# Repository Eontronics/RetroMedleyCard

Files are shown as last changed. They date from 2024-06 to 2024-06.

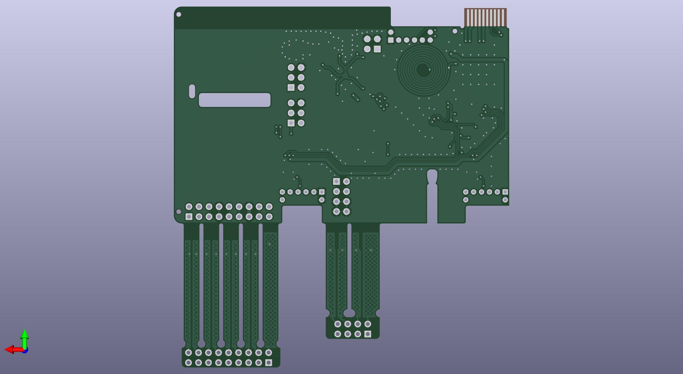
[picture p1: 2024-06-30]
Images/RMC_Back_Ortho.jpg

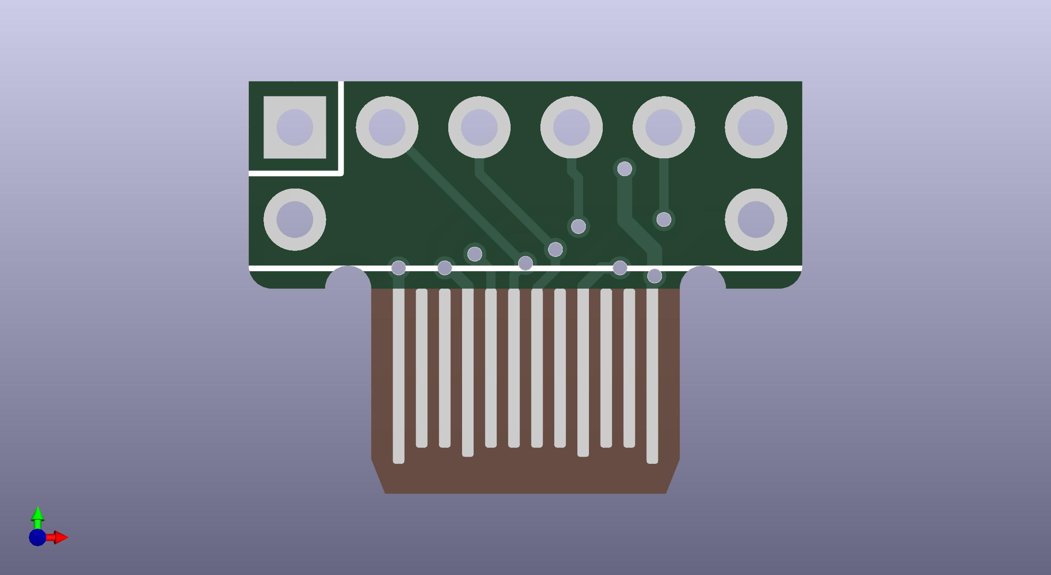
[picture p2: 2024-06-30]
Images/RMC_USBCT_Front_Ortho.jpg

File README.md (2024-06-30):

# RetroMedleyCard
Repository containing the RetroMedleyCard hardware design files.

RetroMedleyCard is a buisiness card sized PCB created for the [Hackaday 2024 Business Card Contest](https://hackaday.io/contest/195949-2024-business-card-contest) that aims to run a range of emulators with support for USB controllers, and output to full sized monitors/TVs, while maintaining a thicnkess <=2.0mm.

The Hackaday.io project page for RetroMedleyCard may be found at https://hackaday.io/project/196328-retromedleycard, which includes images of the physical hardware and testing

# Limitations
The current (first) iteration of RetroMedleyCard is severely limited by the ~2MB of onboard RAM, and various other issues:
* It has been successfully tested running Gameboy emulation without audio output, however other emulators often cause the system to crash immediately.
* The connectors are all formed using specially shaped PCB structures in order to maintain a thin form-factor, however these often fail to make reliable contact for audio, USB-C and SD card connections.
* Display output is limited to ~52fps @320x240 in RGB565, due to difficulty moving pixel data from the RP2040 PIO into the frame-buffer while remaining syncronised with commands sent over the same interface

It is intended to run a modified version of [retro-go](https://github.com/ducalex/retro-go), however firmware is not yet provided as it is currently a mess of rushed tweaks in an attempt to get a functional device.

As a result of these limitations I do not see it being worthwhile to improve the firmware for this version of RetroMedleyCard, as future iterations should aim to adress the lack of available memory, for which a more complete firmware can be written.

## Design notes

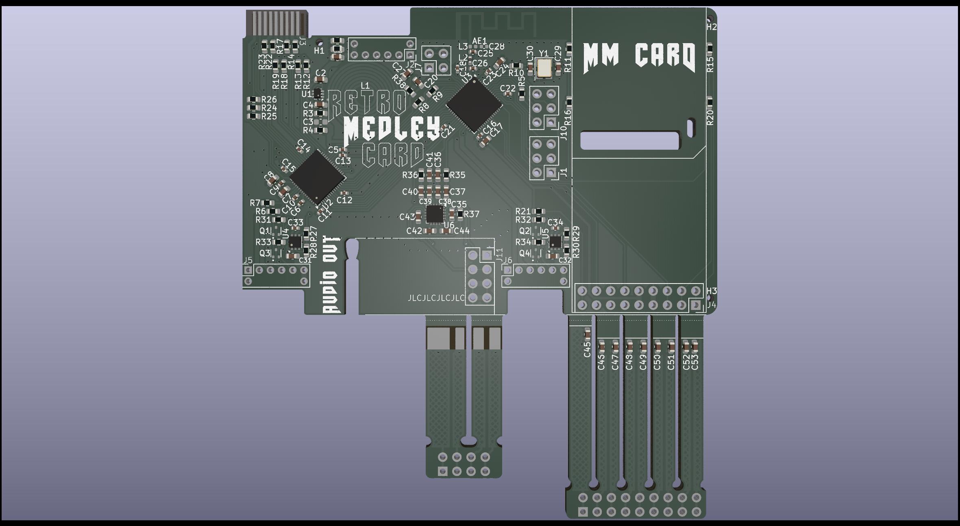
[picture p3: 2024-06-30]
Images/RMC_Front_Render.jpg

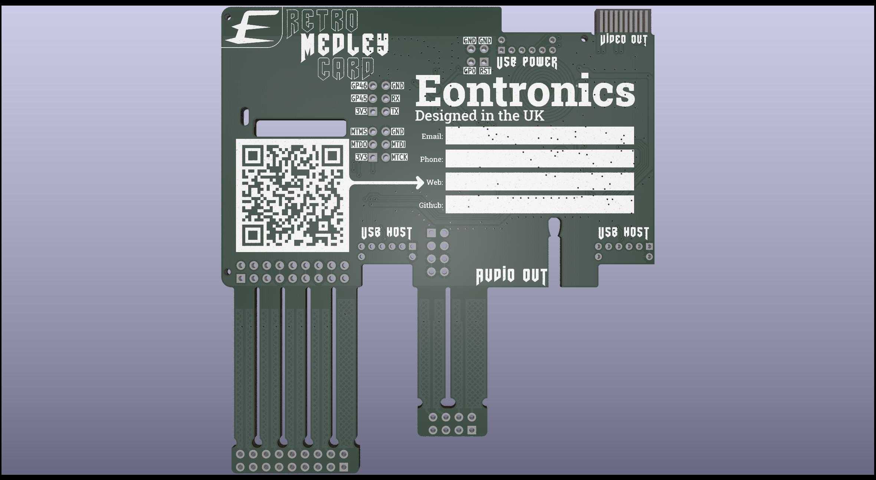
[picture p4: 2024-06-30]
Images/RMC_Back_Render.jpg

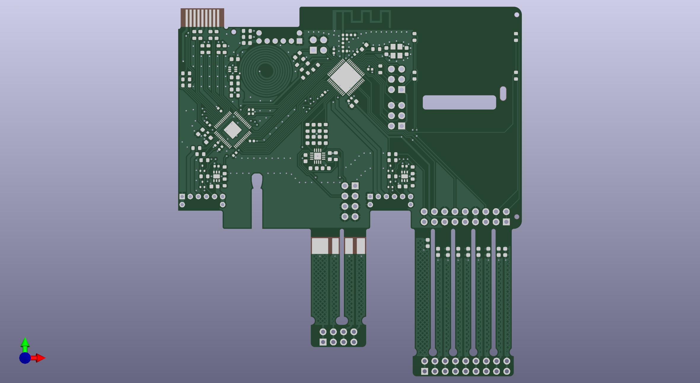
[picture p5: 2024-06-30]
Images/RMC_Front_Ortho.jpg

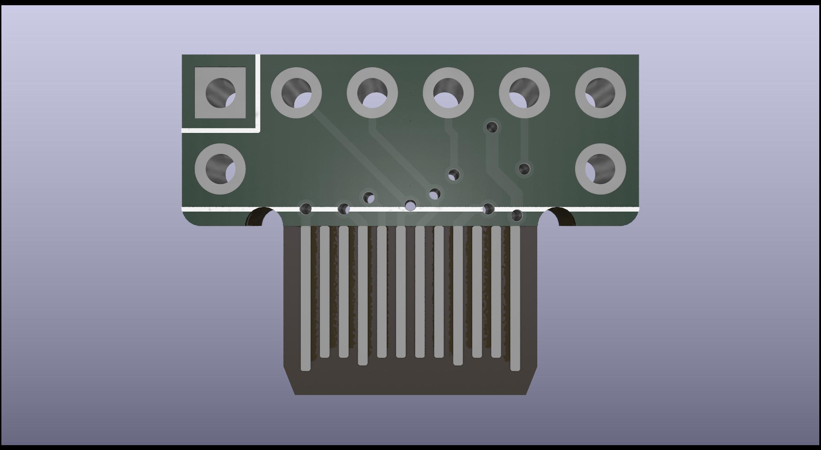
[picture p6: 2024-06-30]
Images/RMC_USBCT_Front_Render.jpg

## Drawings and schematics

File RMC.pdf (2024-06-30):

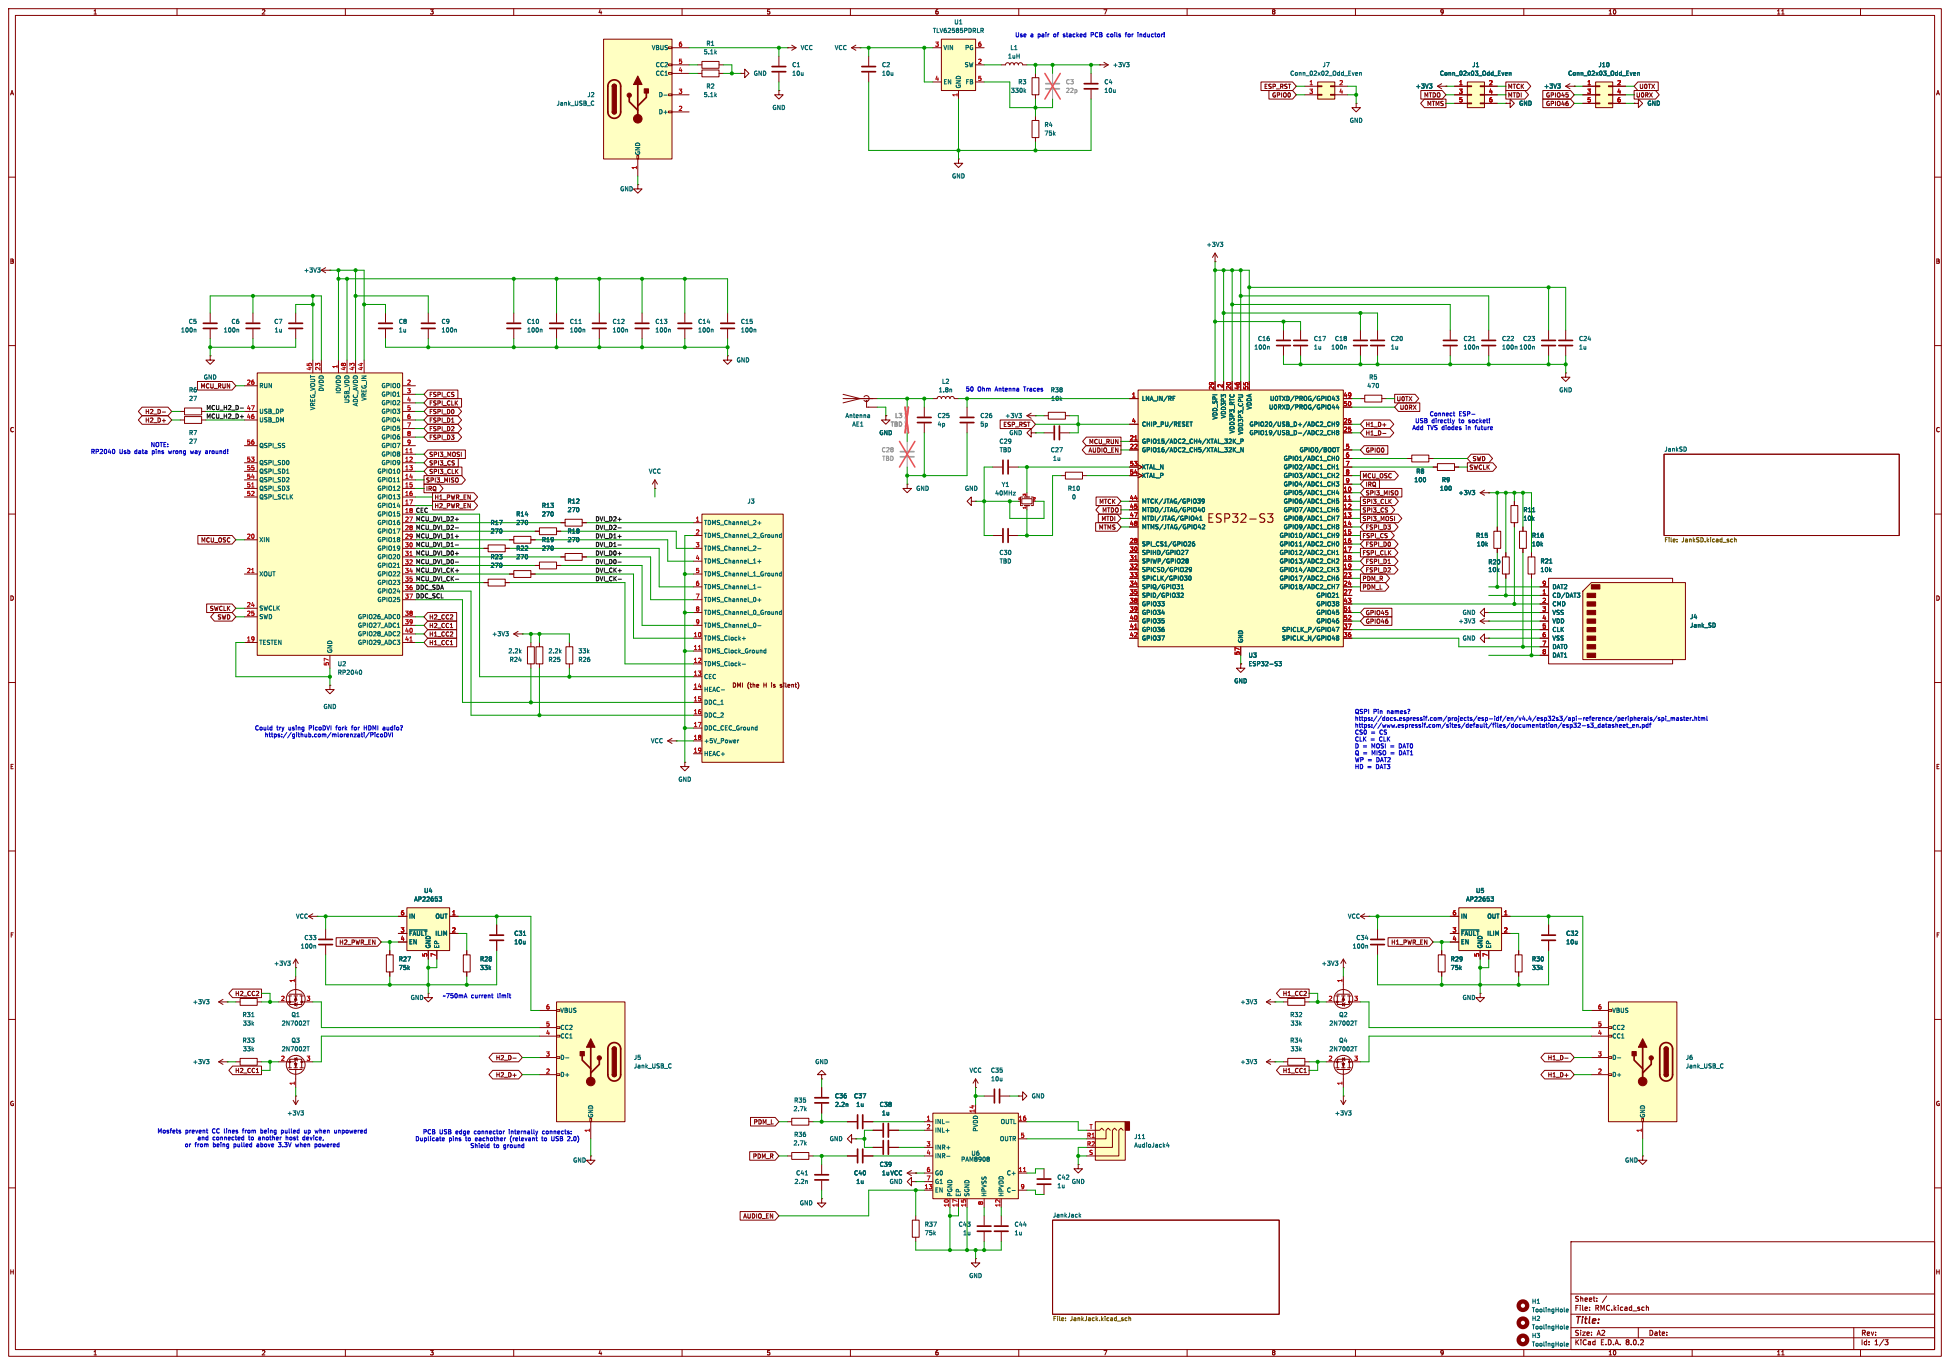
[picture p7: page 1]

1 SW 2 VIN 3 EN 4 FB 5 PG 6 U1 TLV62585PDRLR

Use a pair of stacked PCB coils for inductor! NOTE: RP2040 Usb data pins wrong way around!

GND
100n DMI (the H is silent) TDMS_Channel_2+ 1 TDMS_Clock+ 10 TDMS_Clock_Ground 11 TDMS_Clock- 12 CEC 13 HEAC- 14 DDC_1 15 DDC_2 16 DDC_CEC_Ground 17 +5V_Power 18 HEAC+ 19 TDMS_Channel_2_Ground 2 TDMS_Channel_2- 3 TDMS_Channel_1+ 4 TDMS_Channel_1_Ground 5 TDMS_Channel_1- 6 TDMS_Channel_0+ 7 TDMS_Channel_0_Ground 8 TDMS_Channel_0- 9

QSPI Pin names?
https://docs.espressif.com/projects/esp-idf/en/v4.4/esp32s3/api-reference/peripherals/spi_master.html
https://www.espressif.com/sites/default/files/documentation/esp32-s3_datasheet_en.pdf CS0 = CS CLK = CLK D = MOSI = DAT0 Q = MISO = DAT1 WP = DAT2 HD = DAT3

Could try using PicoDVI fork for HDMI audio?
https://github.com/mlorenzati/PicoDVI

~750mA current limit Mosfets prevent CC lines from being pulled up when unpowered

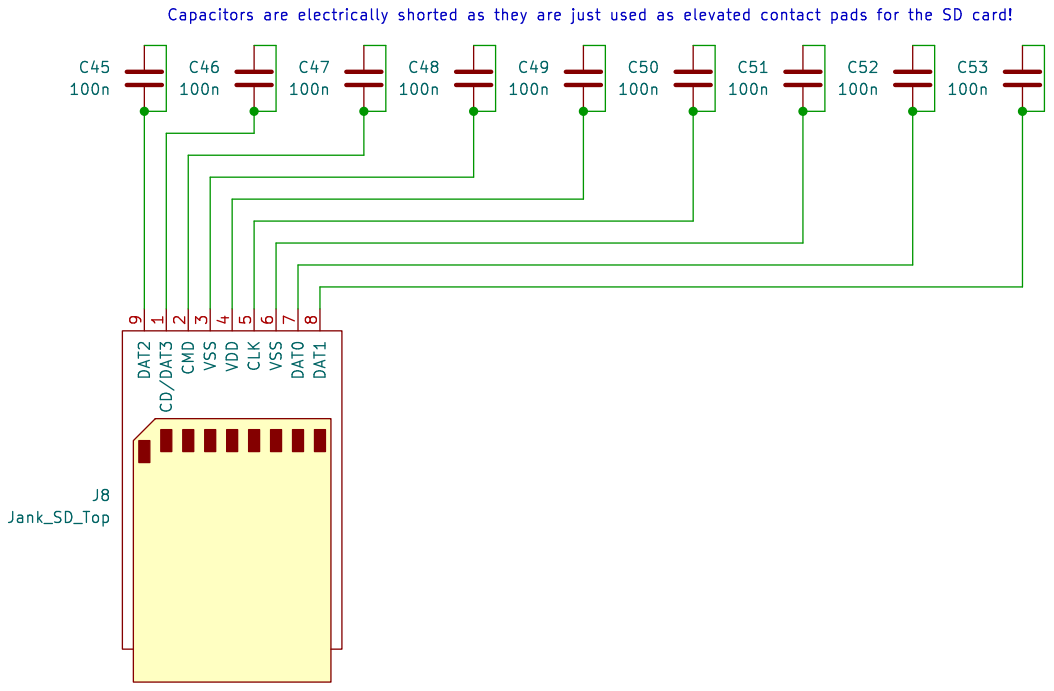
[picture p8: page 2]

1 CMD
Id: 2/3 Title: File: JankSD.kicad_sch Sheet: /JankSD/ CD/DAT3

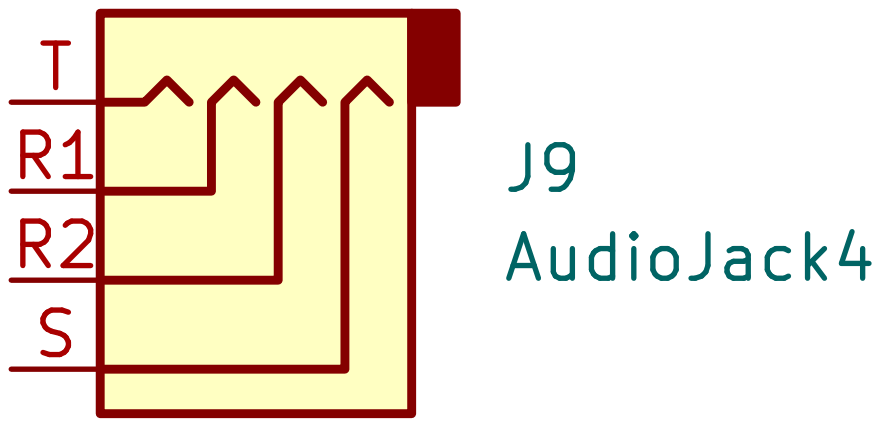
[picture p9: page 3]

Id: 3/3 Title: File: JankJack.kicad_sch Sheet: /JankJack/ R1 R2S

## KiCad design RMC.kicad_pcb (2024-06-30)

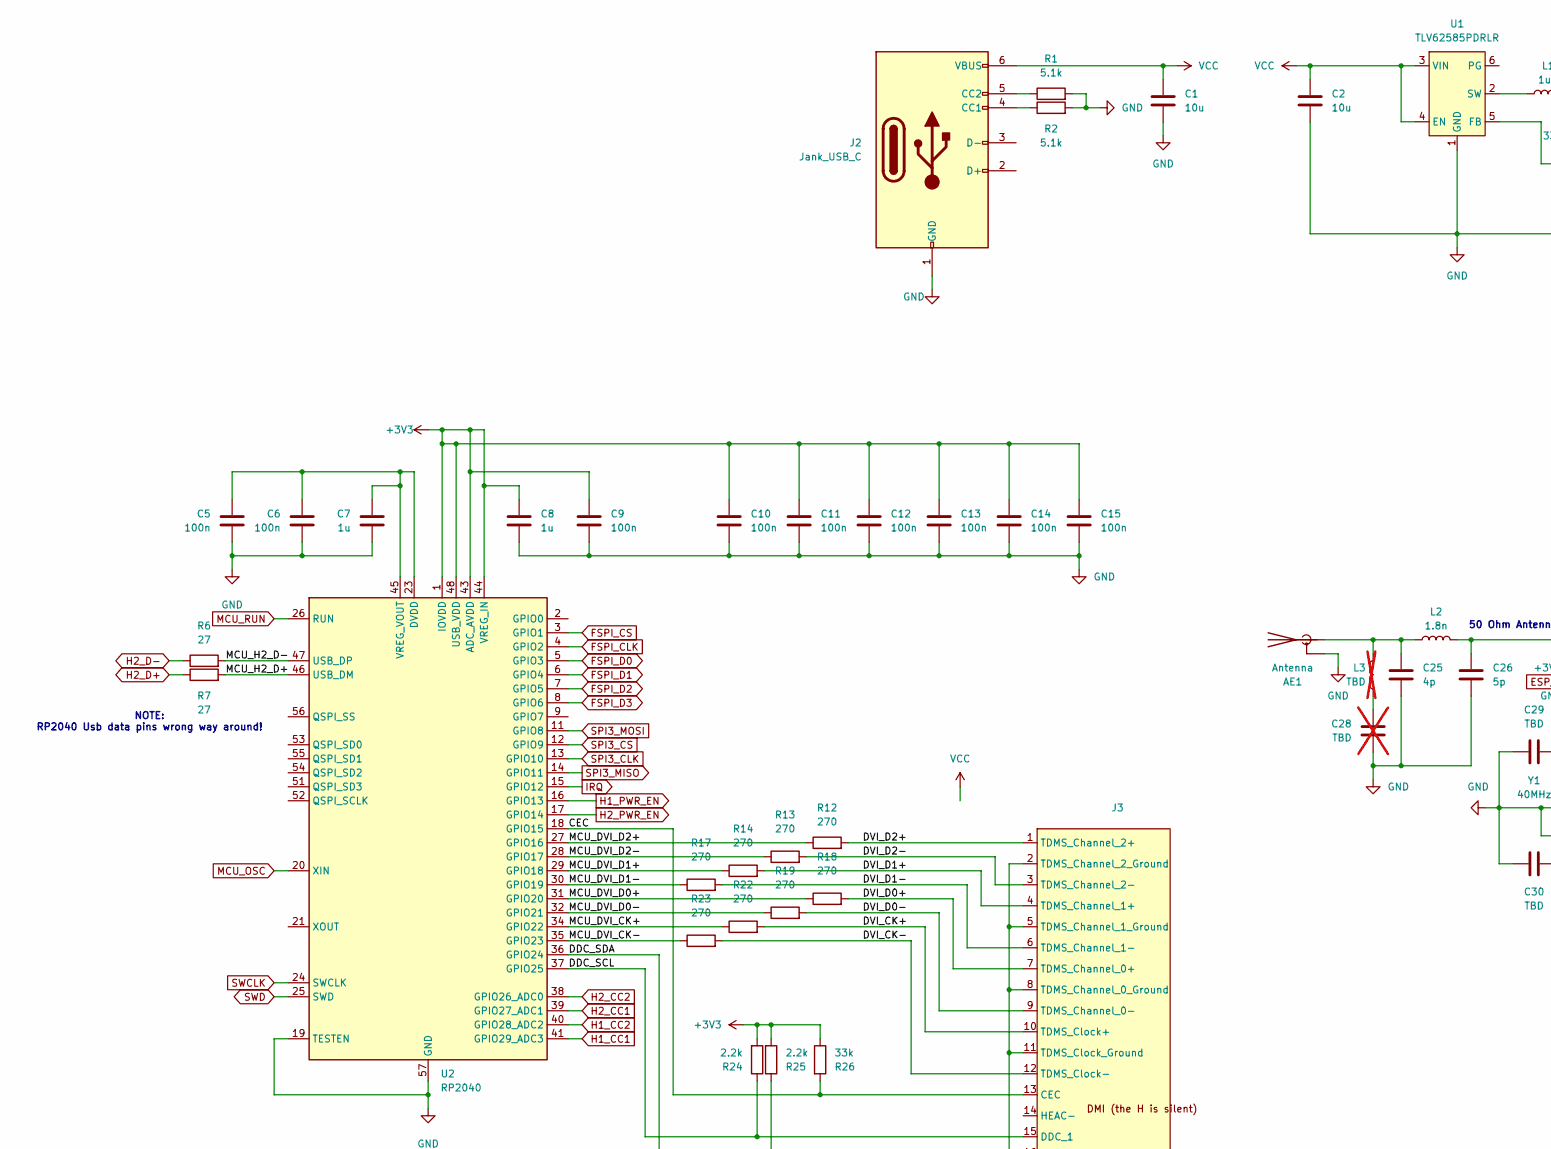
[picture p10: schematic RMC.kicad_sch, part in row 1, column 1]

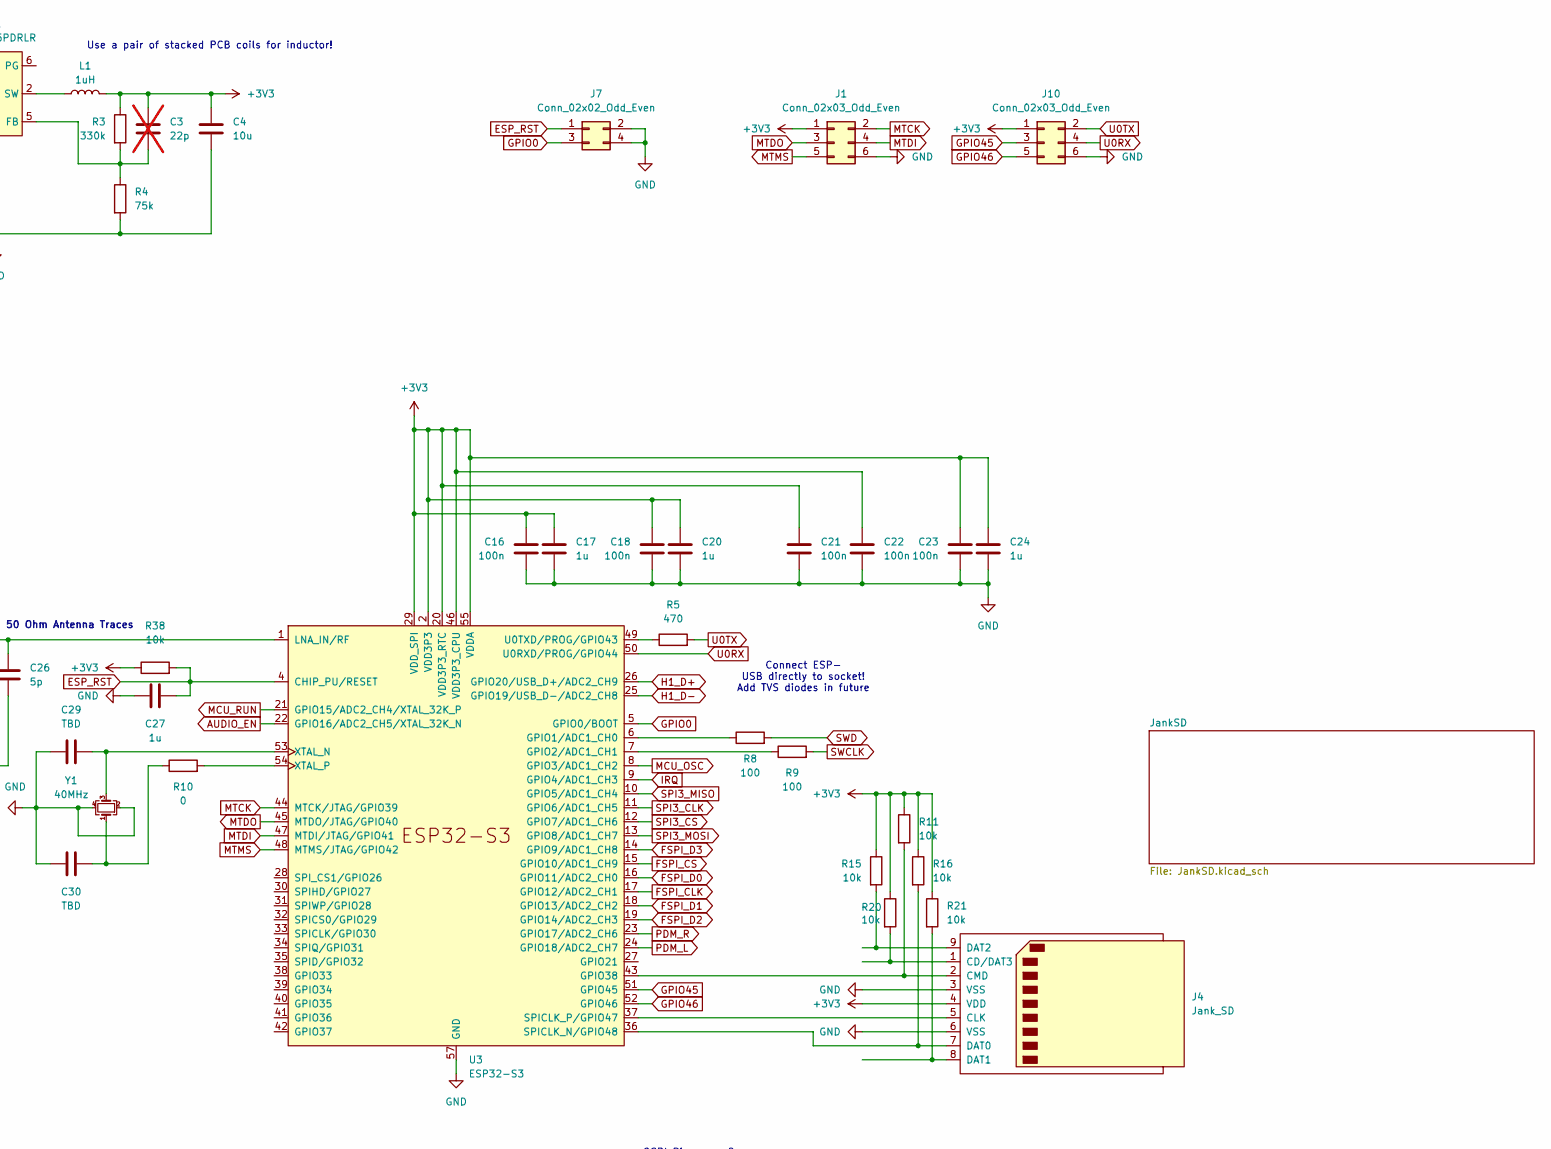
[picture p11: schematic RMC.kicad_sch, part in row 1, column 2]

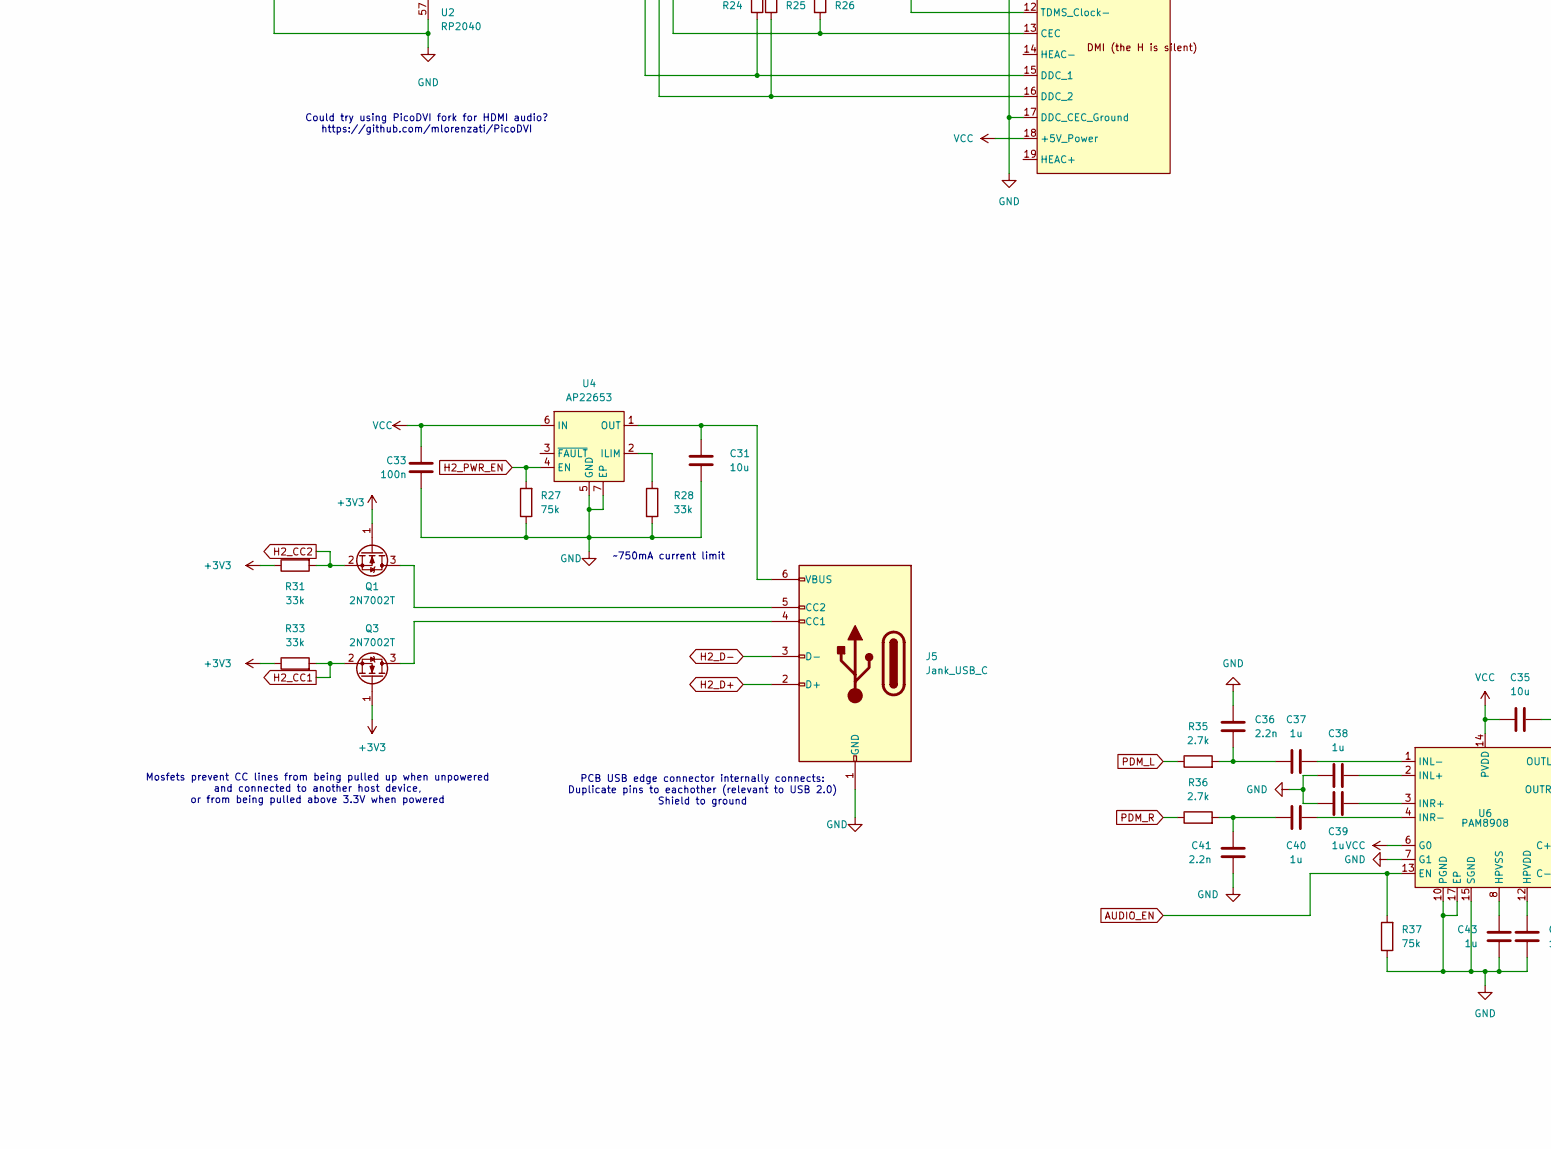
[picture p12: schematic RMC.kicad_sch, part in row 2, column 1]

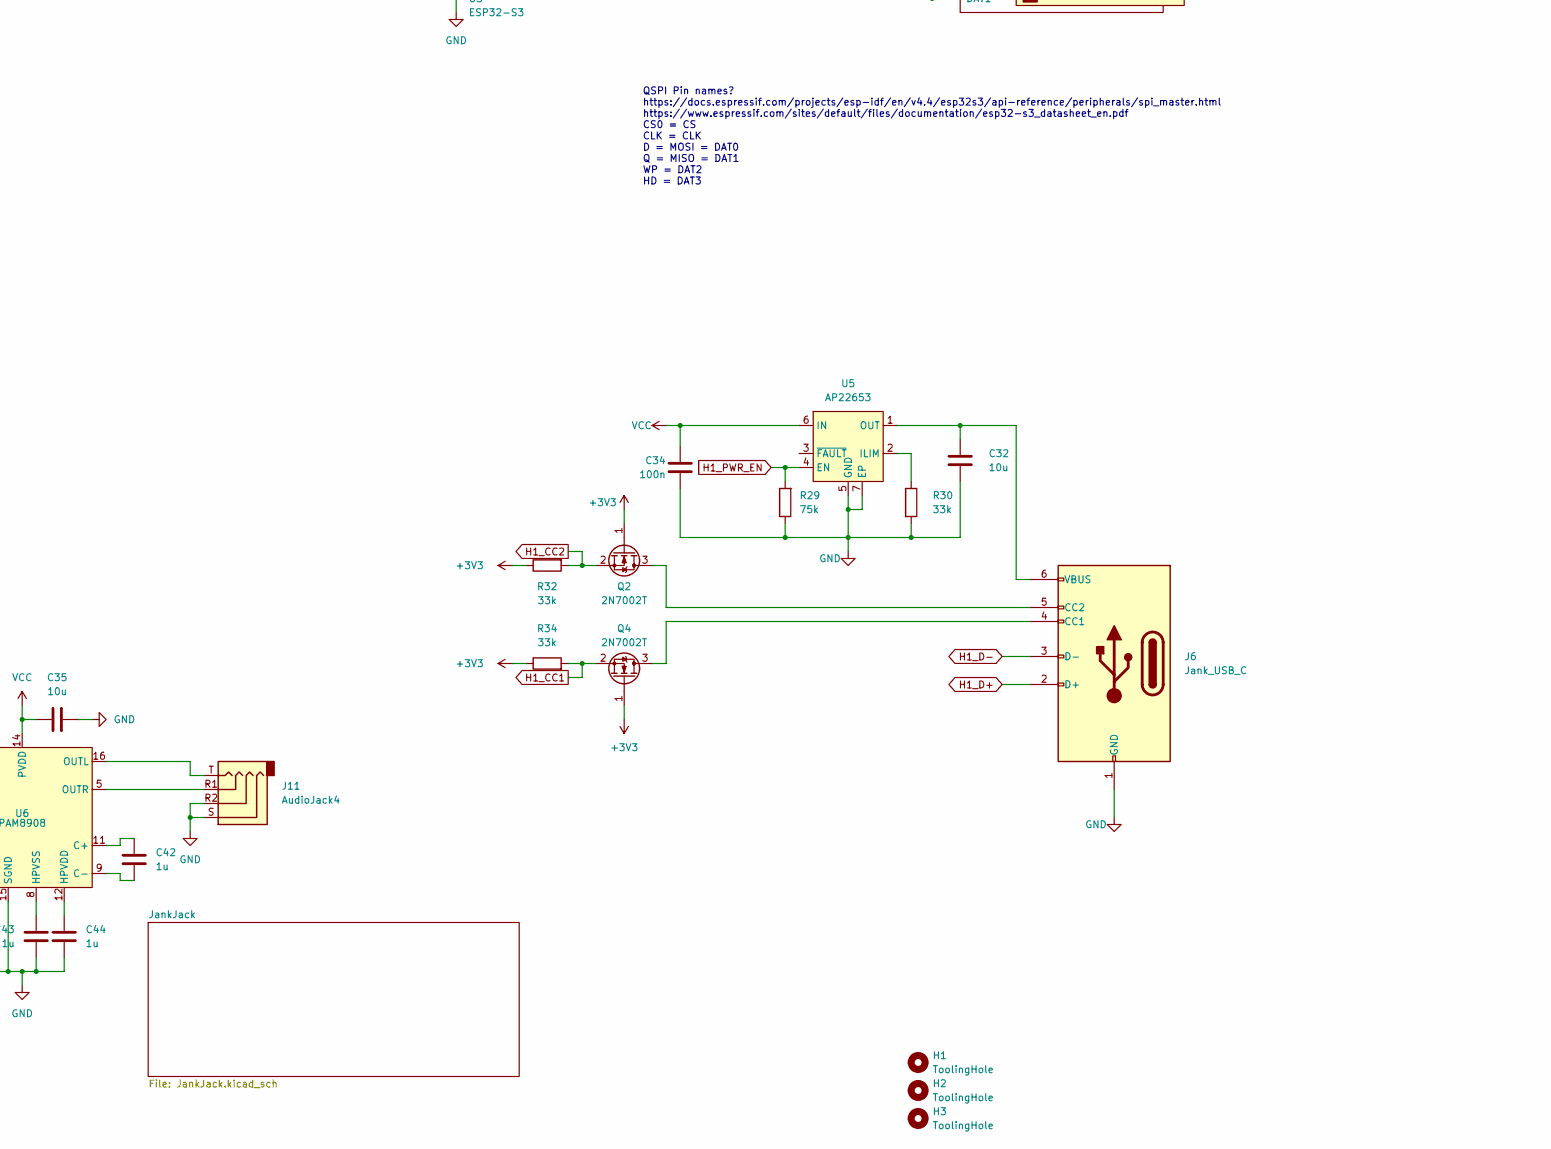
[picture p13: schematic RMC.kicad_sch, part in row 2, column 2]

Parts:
AE1: Antenna; Texas_SWRA117D_2.4GHz_Right
C1, C2, C4, C31, C32, C35: 10u; C_0603_1608Metric
C3: 22p; C_0603_1608Metric; not fitted
C5, C6, C9, C10, C11, C12, C13, C14, C15, C16, C18, C21, C22, C23, C33, C34: 100n; C_0402_1005Metric
C7, C8, C17, C20, C24, C27, C37, C38, C39, C40, C42, C43, C44: 1u; C_0603_1608Metric
C25: 4p; C_0402_1005Metric
C26: 5p; C_0402_1005Metric
C28: TBD; C_0402_1005Metric; not fitted
C29, C30: TBD; C_0603_1608Metric
C36, C41: 2.2n; C_0603_1608Metric
H1, H2, H3: ToolingHole; JLC_Tooling_Hole
J1, J10: Conn_02x03_Odd_Even; PinHeader_2x03_P2.54mm_Vertical
J2, J5, J6: Jank_USB_C; JankUSBCB
J3: PBMI
J4: Jank_SD; JankSDB
J7: Conn_02x02_Odd_Even; PinHeader_2x02_P2.54mm_Vertical
J11: AudioJack4; JankJackB
L1: 1uH; 1uH_12.8mm_PCB_Coil
L2: 1.8n; L_0402_1005Metric
L3: TBD; L_0402_1005Metric; not fitted
Q1, Q2, Q3, Q4: 2N7002T; SOT-523
R1, R2: 5.1k; R_0603_1608Metric
R3: 330k; R_0603_1608Metric
R4, R27, R29, R37: 75k; R_0603_1608Metric
R5: 470; R_0603_1608Metric
R6, R7: 27; R_0603_1608Metric
R8, R9: 100; R_0603_1608Metric
R10: 0; R_0603_1608Metric
R11, R15, R16, R20, R21, R38: 10k; R_0603_1608Metric
R12, R13, R14, R17, R18, R19, R22, R23: 270; R_0603_1608Metric
R24, R25: 2.2k; R_0603_1608Metric
R26, R28, R30, R31, R32, R33, R34: 33k; R_0603_1608Metric
R35, R36: 2.7k; R_0603_1608Metric
U1: TLV62585PDRLR; SOT-563
U2: RP2040; QFN-56-1EP_7x7mm_P0.4mm_EP3.2x3.2mm
U3: ESP32-S3; QFN-56-1EP_7x7mm_P0.4mm_EP5.6x5.6mm
U4, U5: AP22653; DFN-6-1EP_2x2mm_P0.65mm_EP1x1.6mm
U6: PAM8908; QFN-16-1EP_3x3mm_P0.5mm_EP1.7x1.7mm
Y1: 40MHz; Crystal_SMD_3225-4Pin_3.2x2.5mm

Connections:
+3V3: C3.1, C4.1, C8.2, C9.1, C10.1, C11.1, C12.1, C13.1, C14.1, C15.1, C16.2, C17.2, C18.2, C20.2, C21.2, C22.2, C23.2, C24.2, J1.1, J4.4 (VDD), J10.1, L1.1, Q1.1 (G), Q2.1 (G), Q3.1 (G), Q4.1 (G), R3.1, R11.1, R15.1, R16.1, R20.1, R21.1, R24.2, R25.2, R26.1, R31.1, R32.1, R33.1, R34.1, R38.1, U2.1 (IOVDD), U2.10 (IOVDD), U2.22 (IOVDD), U2.33 (IOVDD), U2.42 (IOVDD), U2.43 (ADC_AVDD), U2.44 (VREG_IN), U2.48 (USB_VDD), U2.49 (IOVDD), U3.2 (VDD3P3), U3.3 (VDD3P3), U3.20 (VDD3P3_RTC), U3.29 (VDD_SPI), U3.46 (VDD3P3_CPU), U3.55 (VDDA), U3.56 (VDDA)
/CEC: J3.13 (CEC), R26.2, U2.18 (GPIO15)
/DDC_SCL: J3.15 (DDC_1), R24.1, U2.37 (GPIO25)
/DDC_SDA: J3.16 (DDC_2), R25.1, U2.36 (GPIO24)
/DVI_CK+: J3.10 (TDMS_Clock+), R22.2
/DVI_CK-: J3.12 (TDMS_Clock-), R23.2
/DVI_D0+: J3.7 (TDMS_Channel_0+), R18.2
/DVI_D0-: J3.9 (TDMS_Channel_0-), R19.2
/DVI_D1+: J3.4 (TDMS_Channel_1+), R14.2
/DVI_D1-: J3.6 (TDMS_Channel_1-), R17.2
/DVI_D2+: J3.1 (TDMS_Channel_2+), R12.2
/DVI_D2-: J3.3 (TDMS_Channel_2-), R13.2
/MCU_DVI_CK+: R22.1, U2.34 (GPIO22)
/MCU_DVI_CK-: R23.1, U2.35 (GPIO23)
/MCU_DVI_D0+: R18.1, U2.31 (GPIO20)
/MCU_DVI_D0-: R19.1, U2.32 (GPIO21)
/MCU_DVI_D1+: R14.1, U2.29 (GPIO18)
/MCU_DVI_D1-: R17.1, U2.30 (GPIO19)
/MCU_DVI_D2+: R12.1, U2.27 (GPIO16)
/MCU_DVI_D2-: R13.1, U2.28 (GPIO17)
/MCU_H2_D+: R7.2, U2.46 (USB_DM)
/MCU_H2_D-: R6.2, U2.47 (USB_DP)
AUDIO_EN: R37.2, U3.22 (GPIO16/ADC2_CH5/XTAL_32K_N), U6.13 (EN)
ESP_RST: C27.1, J7.1, R38.2, U3.4 (CHIP_PU/RESET)
FSPI_CLK: U2.4 (GPIO2), U3.17 (GPIO12/ADC2_CH1)
FSPI_CS: U2.3 (GPIO1), U3.15 (GPIO10/ADC1_CH9)
FSPI_D0: U2.5 (GPIO3), U3.16 (GPIO11/ADC2_CH0)
FSPI_D1: U2.6 (GPIO4), U3.18 (GPIO13/ADC2_CH2)
FSPI_D2: U2.7 (GPIO5), U3.19 (GPIO14/ADC2_CH3)
FSPI_D3: U2.8 (GPIO6), U3.14 (GPIO9/ADC1_CH8)
GND: AE1.2 (Shield), C1.1, C2.2, C4.2, C5.2, C6.2, C7.2, C8.1, C9.2, C10.2, C11.2, C12.2, C13.2, C14.2, C15.2, C16.1, C17.1, C18.1, C20.1, C21.1, C22.1, C23.1, C24.1, C25.2, C26.2, C27.2, C28.2, C29.1, C30.1, C31.2, C32.2, C33.2, C34.2, C35.1, C36.1, C38.1, C39.1, C41.2, C43.1, C44.1, J1.6, J2.1 (GND), J3.2 (TDMS_Channel_2_Ground), J3.5 (TDMS_Channel_1_Ground), J3.8 (TDMS_Channel_0_Ground), J3.11 (TDMS_Clock_Ground), J3.17 (DDC_CEC_Ground), J4.3 (VSS), J4.6 (VSS), J5.1 (GND), J6.1 (GND), J7.2, J7.4, J10.6, J11.R2, J11.S, R1.2, R2.2, R4.2, R27.1, R28.2, R29.1, R30.2, R37.1, U1.1 (GND), U2.19 (TESTEN), U2.57 (GND), U3.57 (GND), U4.5 (GND), U4.7 (EP), U5.5 (GND), U5.7 (EP), U6.7 (G1), U6.10 (PGND), U6.15 (SGND), U6.17 (EP), Y1.2, Y1.4
GPIO0: J7.3, U3.5 (GPIO0/BOOT)
GPIO45: J10.3, U3.51 (GPIO45)
GPIO46: J10.5, U3.52 (GPIO46)
H1_CC1: Q4.2 (S), R34.2, U2.41 (GPIO29_ADC3)
H1_CC2: Q2.2 (S), R32.2, U2.40 (GPIO28_ADC2)
H1_D+: J6.2 (D+), U3.26 (GPIO20/USB_D+/ADC2_CH9)
H1_D-: J6.3 (D-), U3.25 (GPIO19/USB_D-/ADC2_CH8)
H1_PWR_EN: R29.2, U2.16 (GPIO13), U5.4 (EN)
H2_CC1: Q3.2 (S), R33.2, U2.39 (GPIO27_ADC1)
H2_CC2: Q1.2 (S), R31.2, U2.38 (GPIO26_ADC0)
H2_D+: J5.2 (D+), R7.1
H2_D-: J5.3 (D-), R6.1
H2_PWR_EN: R27.2, U2.17 (GPIO14), U4.4 (EN)
IRQ: U2.15 (GPIO12), U3.9 (GPIO4/ADC1_CH3)
MCU_OSC: U2.20 (XIN), U3.8 (GPIO3/ADC1_CH2)
MCU_RUN: U2.26 (RUN), U3.21 (GPIO15/ADC2_CH4/XTAL_32K_P)
MTCK: J1.2, U3.44 (MTCK/JTAG/GPIO39)
MTDI: J1.4, U3.47 (MTDI/JTAG/GPIO41)
MTDO: J1.3, U3.45 (MTDO/JTAG/GPIO40)
MTMS: J1.5, U3.48 (MTMS/JTAG/GPIO42)
unnamed: AE1.1 (A), C25.1, L2.1, L3.2
unnamed: C28.1, L3.1
unnamed: C30.2, R10.1, Y1.1
unnamed: C36.2, C37.1, R35.2
unnamed: C40.1, C41.1, R36.2
unnamed: J2.4 (CC1), R2.1
unnamed: J2.5 (CC2), R1.1
unnamed: J4.1 (CD/DAT3), R20.2
unnamed: J4.5 (CLK), U3.37 (SPICLK_P/GPIO47)
unnamed: J4.2 (CMD), R11.2, U3.43 (GPIO38)
unnamed: J4.7 (DAT0), R16.2, U3.36 (SPICLK_N/GPIO48)
unnamed: J4.8 (DAT1), R21.2
unnamed: J4.9 (DAT2), R15.2
unnamed: J5.4 (CC1), Q3.3 (D)
unnamed: J5.5 (CC2), Q1.3 (D)
unnamed: C31.1, J5.6 (VBUS), U4.1 (OUT)
unnamed: J6.4 (CC1), Q4.3 (D)
unnamed: J6.5 (CC2), Q2.3 (D)
unnamed: C32.1, J6.6 (VBUS), U5.1 (OUT)
unnamed: C3.2, R3.2, R4.1, U1.5 (FB)
unnamed: L1.2, U1.2 (SW)
unnamed: C5.1, C6.1, C7.1, U2.23 (DVDD), U2.45 (VREG_VOUT), U2.50 (DVDD)
unnamed: R8.1, U3.6 (GPIO1/ADC1_CH0)
unnamed: R9.1, U3.7 (GPIO2/ADC1_CH1)
unnamed: C26.1, L2.2, U3.1 (LNA_IN/RF)
unnamed: R5.1, U3.49 (U0TXD/PROG/GPIO43)
unnamed: C29.2, U3.53 (XTAL_N), Y1.3
unnamed: R10.2, U3.54 (XTAL_P)
unnamed: R28.1, U4.2 (ILIM)
unnamed: R30.1, U5.2 (ILIM)
unnamed: C42.2, U6.11 (C+)
unnamed: C42.1, U6.9 (C-)
unnamed: C44.2, U6.12 (HPVDD)
unnamed: C43.2, U6.8 (HPVSS)
unnamed: C38.2, U6.2 (INL+)
unnamed: C37.2, U6.1 (INL-)
unnamed: C39.2, U6.3 (INR+)
unnamed: C40.2, U6.4 (INR-)
unnamed: J11.T, U6.16 (OUTL)
unnamed: J11.R1, U6.5 (OUTR)
PDM_L: R35.1, U3.24 (GPIO18/ADC2_CH7)
PDM_R: R36.1, U3.23 (GPIO17/ADC2_CH6)
SPI3_CLK: U2.13 (GPIO10), U3.11 (GPIO6/ADC1_CH5)
SPI3_CS: U2.12 (GPIO9), U3.12 (GPIO7/ADC1_CH6)
SPI3_MISO: U2.14 (GPIO11), U3.10 (GPIO5/ADC1_CH4)
SPI3_MOSI: U2.11 (GPIO8), U3.13 (GPIO8/ADC1_CH7)
SWCLK: R9.2, U2.24 (SWCLK)
SWD: R8.2, U2.25 (SWD)
U0RX: J10.4, U3.50 (U0RXD/PROG/GPIO44)
U0TX: J10.2, R5.2
VCC: C1.2, C2.1, C33.1, C34.1, C35.2, J2.6 (VBUS), J3.18 (+5V_Power), U1.3 (VIN), U1.4 (EN), U4.6 (IN), U5.6 (IN), U6.6 (G0), U6.14 (PVDD)

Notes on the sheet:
QSPI Pin names? https://docs.espressif.com/projects/esp-idf/en/v4.4/esp32s3/api-reference/peripherals/spi_master.html https://www.espressif.com/sites/default/files/documentation/esp32-s3_datasheet_en.pdf CS0 = CS CLK = CLK D = MOSI = DAT0 Q = MISO = DAT1 WP = DAT2 HD = DAT3
Use a pair of stacked PCB coils for inductor!
~750mA current limit
Connect ESP- USB directly to socket! Add TVS diodes in future
Could try using PicoDVI fork for HDMI audio? https://github.com/mlorenzati/PicoDVI
50 Ohm Antenna Traces
Mosfets prevent CC lines from being pulled up when unpowered and connected to another host device, or from being pulled above 3.3V when powered
NOTE: RP2040 Usb data pins wrong way around!
PCB USB edge connector internally connects: Duplicate pins to eachother (relevant to USB 2.0) Shield to ground

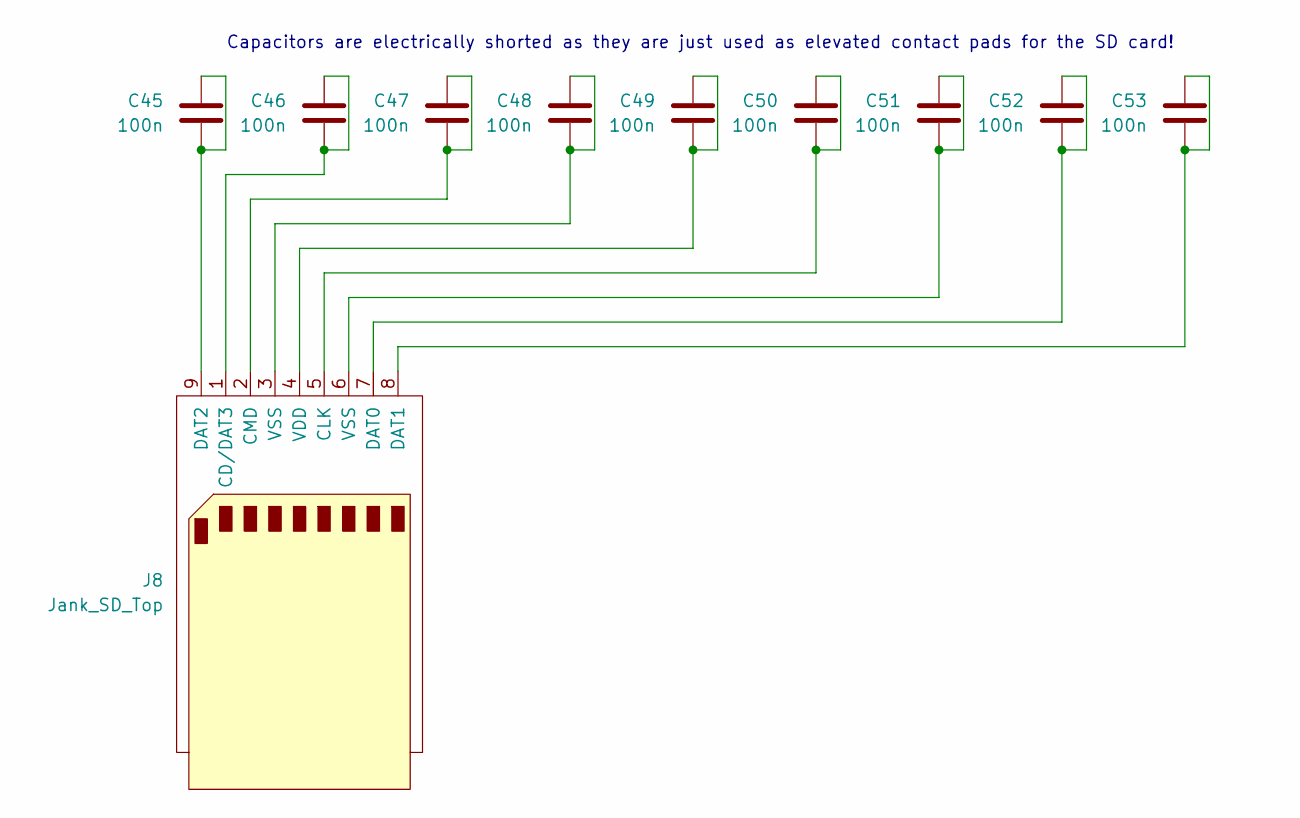
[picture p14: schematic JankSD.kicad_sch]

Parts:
C45, C46, C47, C48, C49, C50, C51, C52, C53: 100n; C_0603_1608Metric
J8: Jank_SD_Top; JankSDT

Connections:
unnamed: C48.1, C48.2, J8.3 (VSS)
unnamed: C51.1, C51.2, J8.6 (VSS)
unnamed: C46.1, C46.2, J8.1 (CD/DAT3)
unnamed: C50.1, C50.2, J8.5 (CLK)
unnamed: C47.1, C47.2, J8.2 (CMD)
unnamed: C52.1, C52.2, J8.7 (DAT0)
unnamed: C53.1, C53.2, J8.8 (DAT1)
unnamed: C45.1, C45.2, J8.9 (DAT2)
unnamed: C49.1, C49.2, J8.4 (VDD)

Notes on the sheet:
Capacitors are electrically shorted as they are just used as elevated contact pads for the SD card!

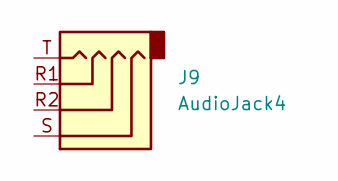
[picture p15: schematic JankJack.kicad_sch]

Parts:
J9: AudioJack4; JankJackT

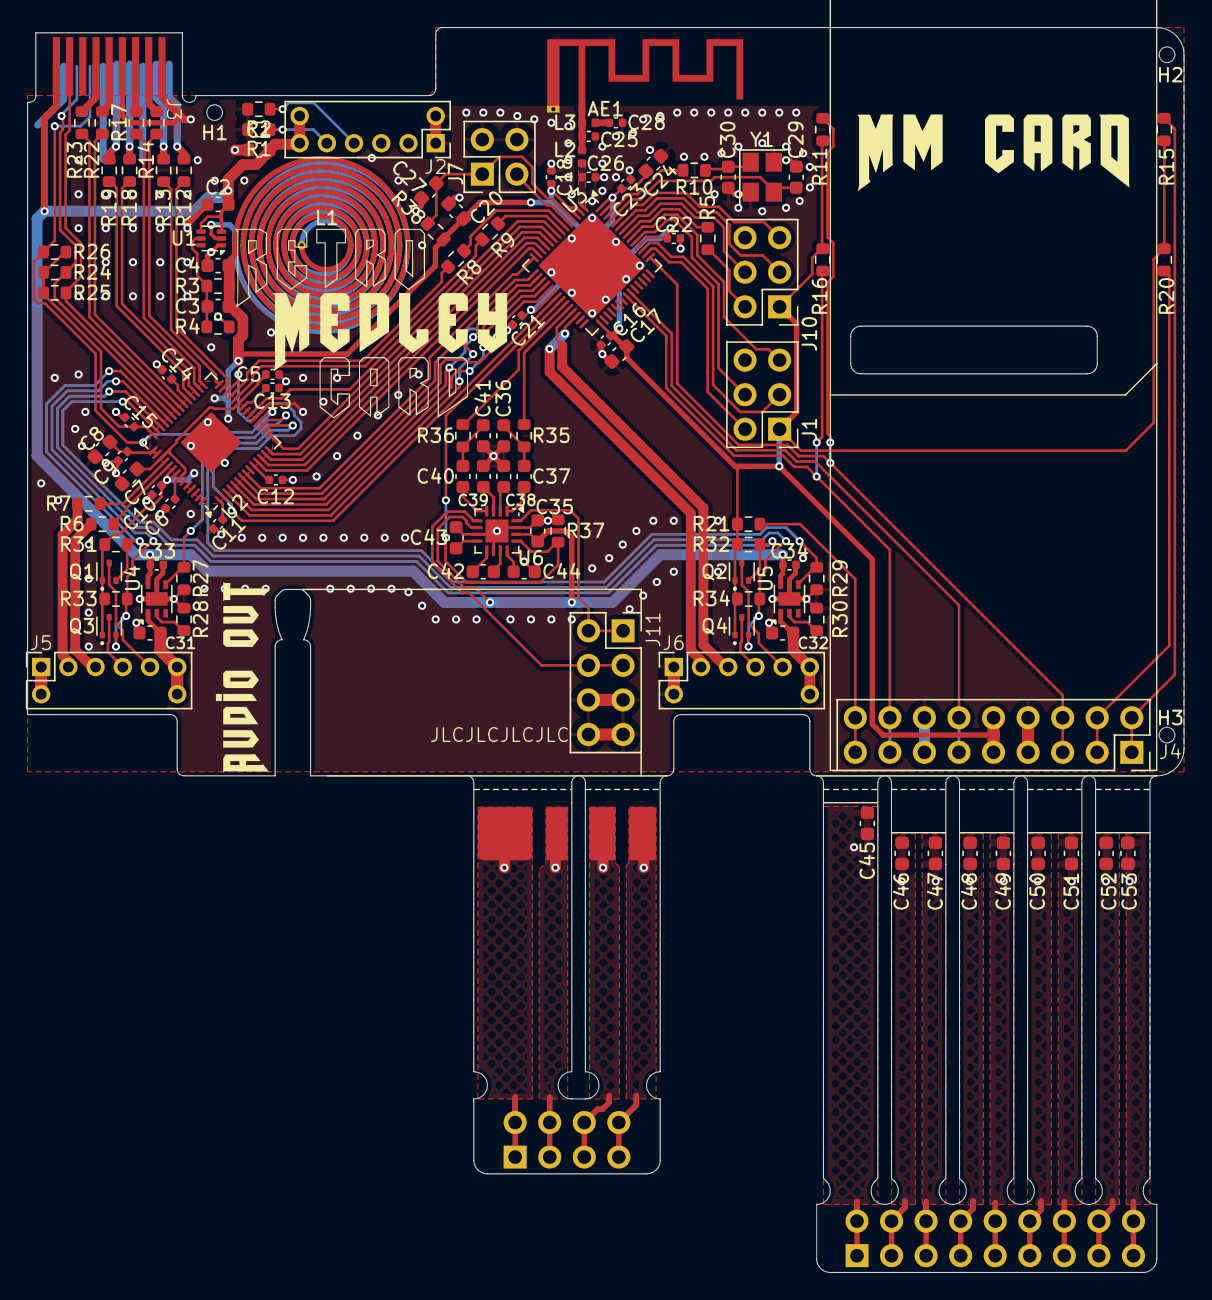
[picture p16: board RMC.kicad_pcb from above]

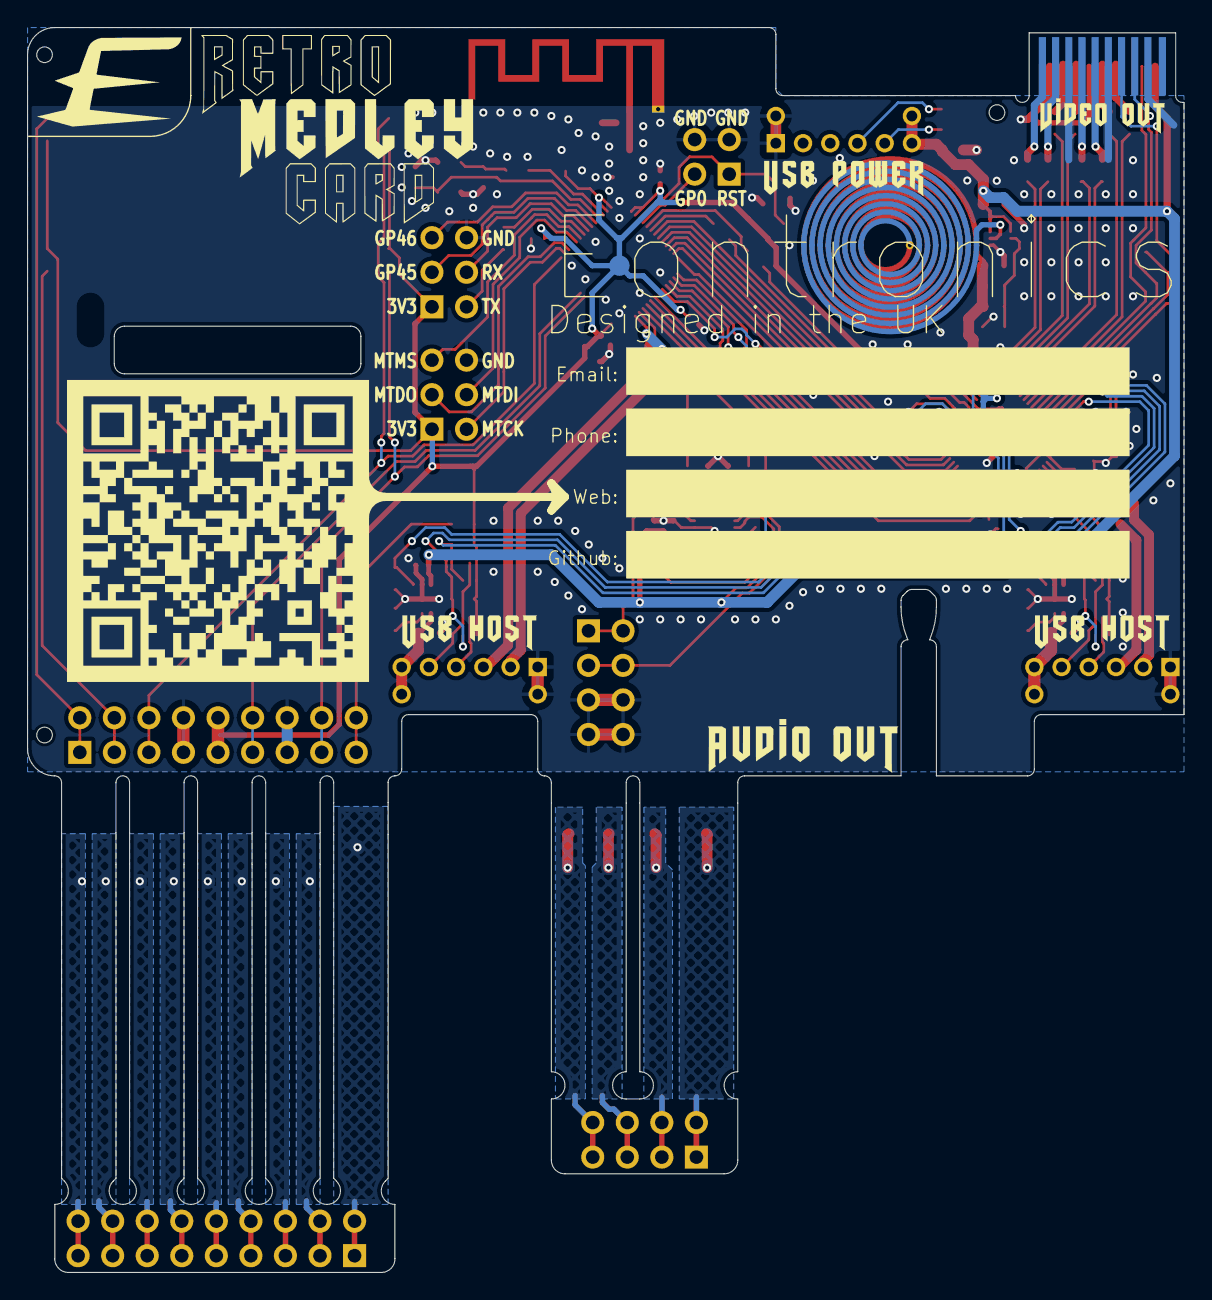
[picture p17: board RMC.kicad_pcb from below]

Board: 2 copper layers, 85.0 x 91.5 mm, 120 parts (3 on the bottom side), 111 nets.

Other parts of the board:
QR*****: Example_QR_Code_22mm
